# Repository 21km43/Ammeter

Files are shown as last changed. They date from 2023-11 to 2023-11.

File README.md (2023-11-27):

# Ammeter
[INA226](https://datasheet.lcsc.com/lcsc/1809192224_Texas-Instruments-INA226AIDGSR_C49851.pdf)を利用した電流計。主にマイコンの消費電流の測定に利用する。  
性能は以下の通り。動作確認済み。
* 入力電圧: 0~36V
* シャント抵抗値: 100mΩ
* 分解能: 25µA
* 電流上限: 819.2mA

ヒューズは入れていないので過電流には注意すること。  
基板CADは[KiCAD](kicad.org)。また、ガーバーファイルはproduction以下に配置した。JLCPCBにアップロードすればすぐに発注可能。

## LICENSE
[MIT LICENSE](/LICENSE)

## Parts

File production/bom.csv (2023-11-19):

Designator | Footprint | Quantity | Value | LCSC Part #
C1, C2 | 0402 | 2 | 0.1u | C1525
R1 | 2512 | 1 | 100m | C326592
R2, R3 | 0603 | 2 | 4.7 | C23164
R4, R5, R6, R7, R8 | 0402 | 5 | 10k | C25744
U1 | VSSOP-10_3x3mm_P0.5mm | 1 | INA226 | C49851

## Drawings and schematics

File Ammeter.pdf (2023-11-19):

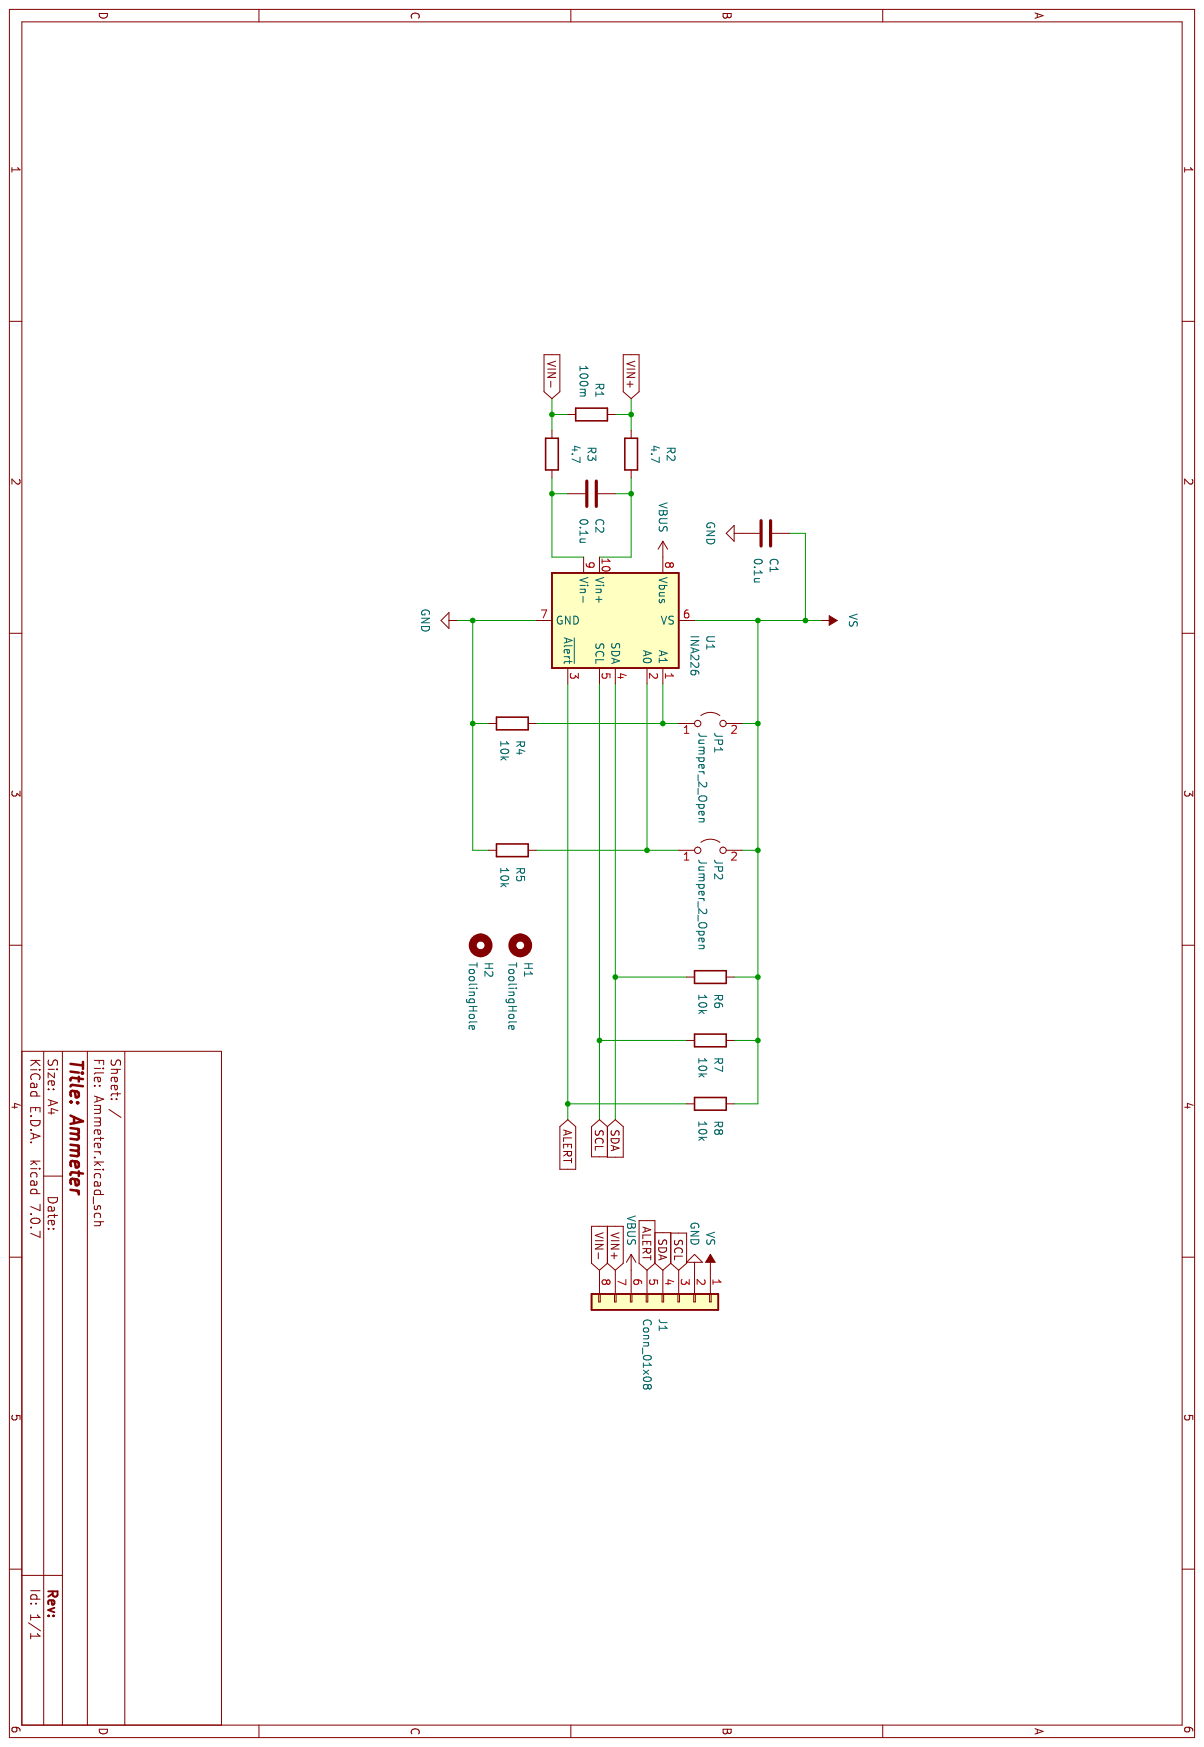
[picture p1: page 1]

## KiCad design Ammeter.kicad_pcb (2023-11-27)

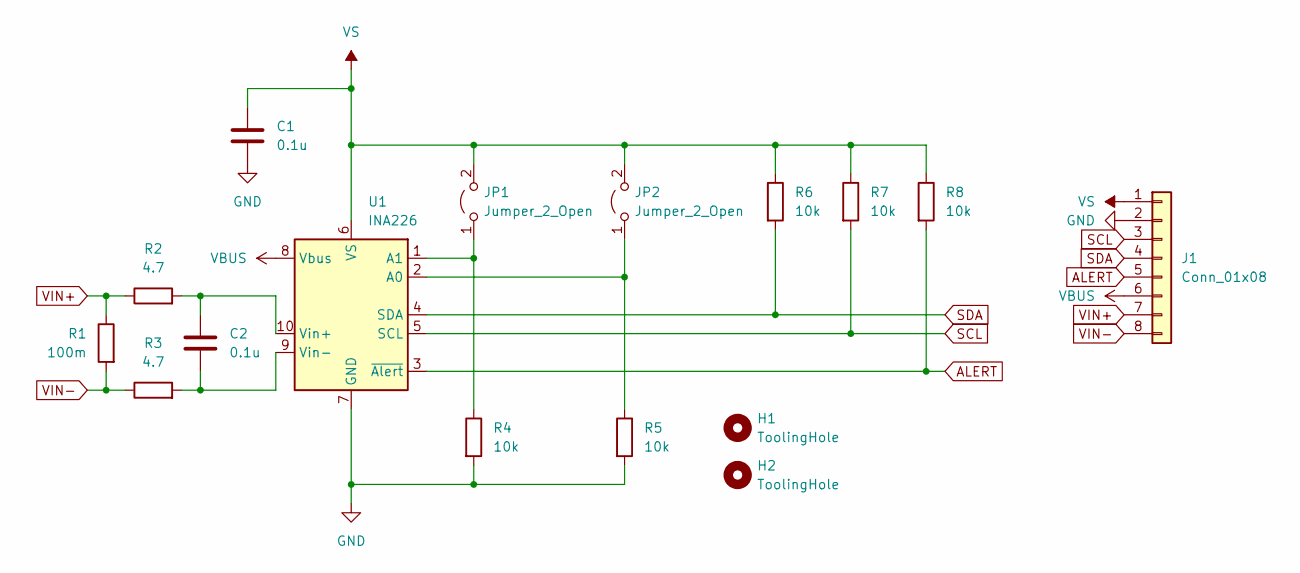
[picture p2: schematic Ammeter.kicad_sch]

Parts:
C1, C2: 0.1u; C_0402_1005Metric; LCSC C1525
H1, H2: ToolingHole; Tooling_Hole
J1: Conn_01x08; PinHeader_1x08_P2.54mm_Vertical
JP1, JP2: Jumper_2_Open; SolderJumper-2_P1.3mm_Open_RoundedPad1.0x1.5mm
R1: 100m; R_2512_6332Metric; LCSC C326592
R2, R3: 4.7; R_0603_1608Metric; LCSC C23164
R4, R5, R6, R7, R8: 10k; R_0402_1005Metric; LCSC C25744
U1: INA226; VSSOP-10_3x3mm_P0.5mm; LCSC C49851

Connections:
ALERT: J1.5, R8.2, U1.3 (~Alert)
GND: C1.2, J1.2, R4.2, R5.2, U1.7 (GND)
unnamed: JP1.1 (A), R4.1, U1.1 (A1)
unnamed: JP2.1 (A), R5.1, U1.2 (A0)
unnamed: C2.1, R2.2, U1.10 (Vin+)
unnamed: C2.2, R3.2, U1.9 (Vin-)
SCL: J1.3, R7.2, U1.5 (SCL)
SDA: J1.4, R6.2, U1.4 (SDA)
VBUS: J1.6, U1.8 (Vbus)
VIN+: J1.7, R1.1, R2.1
VIN-: J1.8, R1.2, R3.1
VS: C1.1, J1.1, JP1.2 (B), JP2.2 (B), R6.1, R7.1, R8.1, U1.6 (VS)

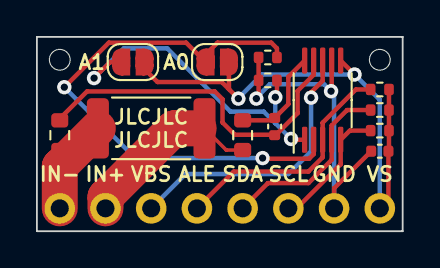
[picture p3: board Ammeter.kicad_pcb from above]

Board: 2 copper layers, 20.3 x 10.8 mm, 16 parts (1 on the bottom side), 12 nets.
